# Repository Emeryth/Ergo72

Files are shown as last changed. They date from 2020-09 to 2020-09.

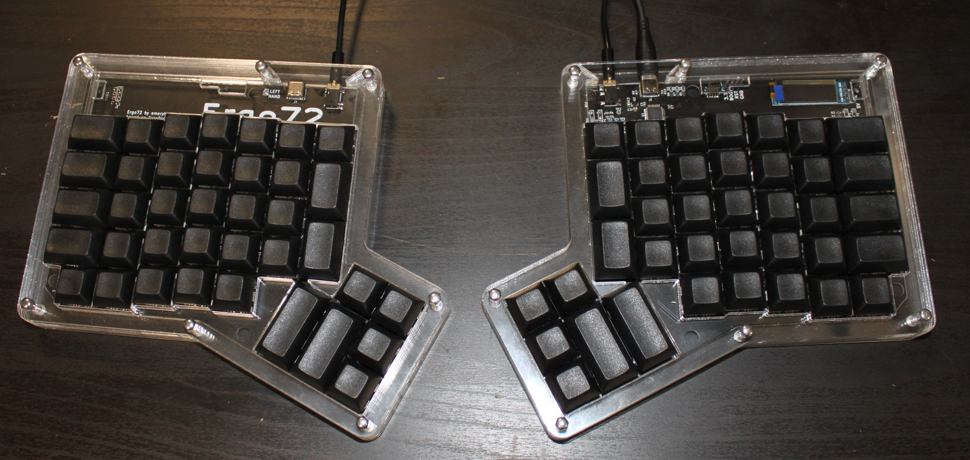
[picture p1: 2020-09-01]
pics/ergo72.jpg

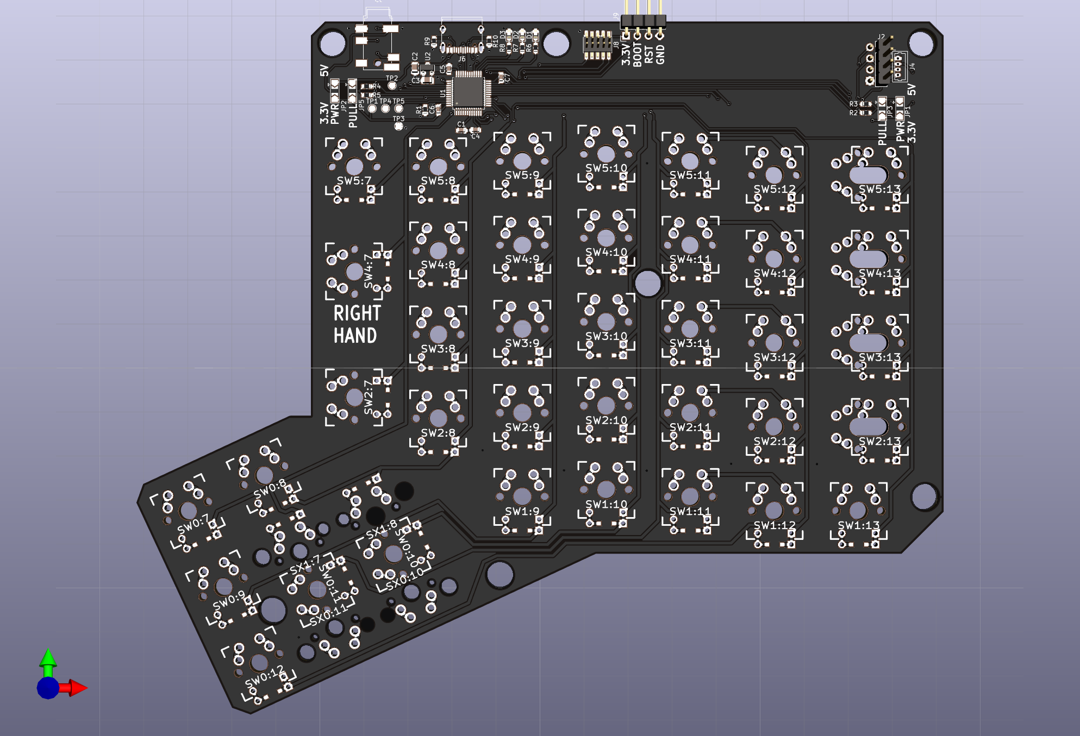
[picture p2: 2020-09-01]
pics/ErgoDOX.png

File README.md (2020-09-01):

# Ergo72

A redesigned ErgoDox keyboard PCB.
Check out [https://emeryth.net/ergo72-keyboard/](https://emeryth.net/ergo72-keyboard/) for more info.

Design features:

* Same key layout as the original Ergodox
* STM32 microcontroller (STM32F072)
* MCU in both halves allowing independent operation
* USB-C
* All components on PCB, no modules
* Extension header for OLED screen or anything else
* Single PCB for both hands
* QMK firmware supported

Basic acrylic case design included.

QMK firmware: [https://github.com/Emeryth/qmk_firmware/tree/ergo72](https://github.com/Emeryth/qmk_firmware/tree/ergo72)

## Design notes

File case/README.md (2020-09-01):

Acrylic case based on the original Ergodox case by Litster.

Layer stackup and thickness, from top to bottom:

1. Top 3mm
2. Spacer 4mm
3. Plate 4mm
4. Spacer 4mm
5. PCB support 3mm 
6. Bottom 3mm

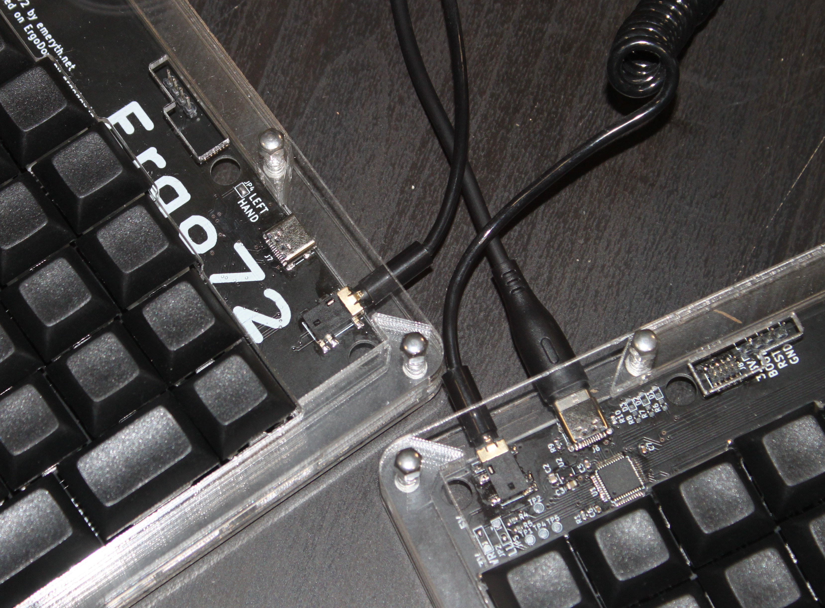
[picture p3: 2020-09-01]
pics/closeup.jpg

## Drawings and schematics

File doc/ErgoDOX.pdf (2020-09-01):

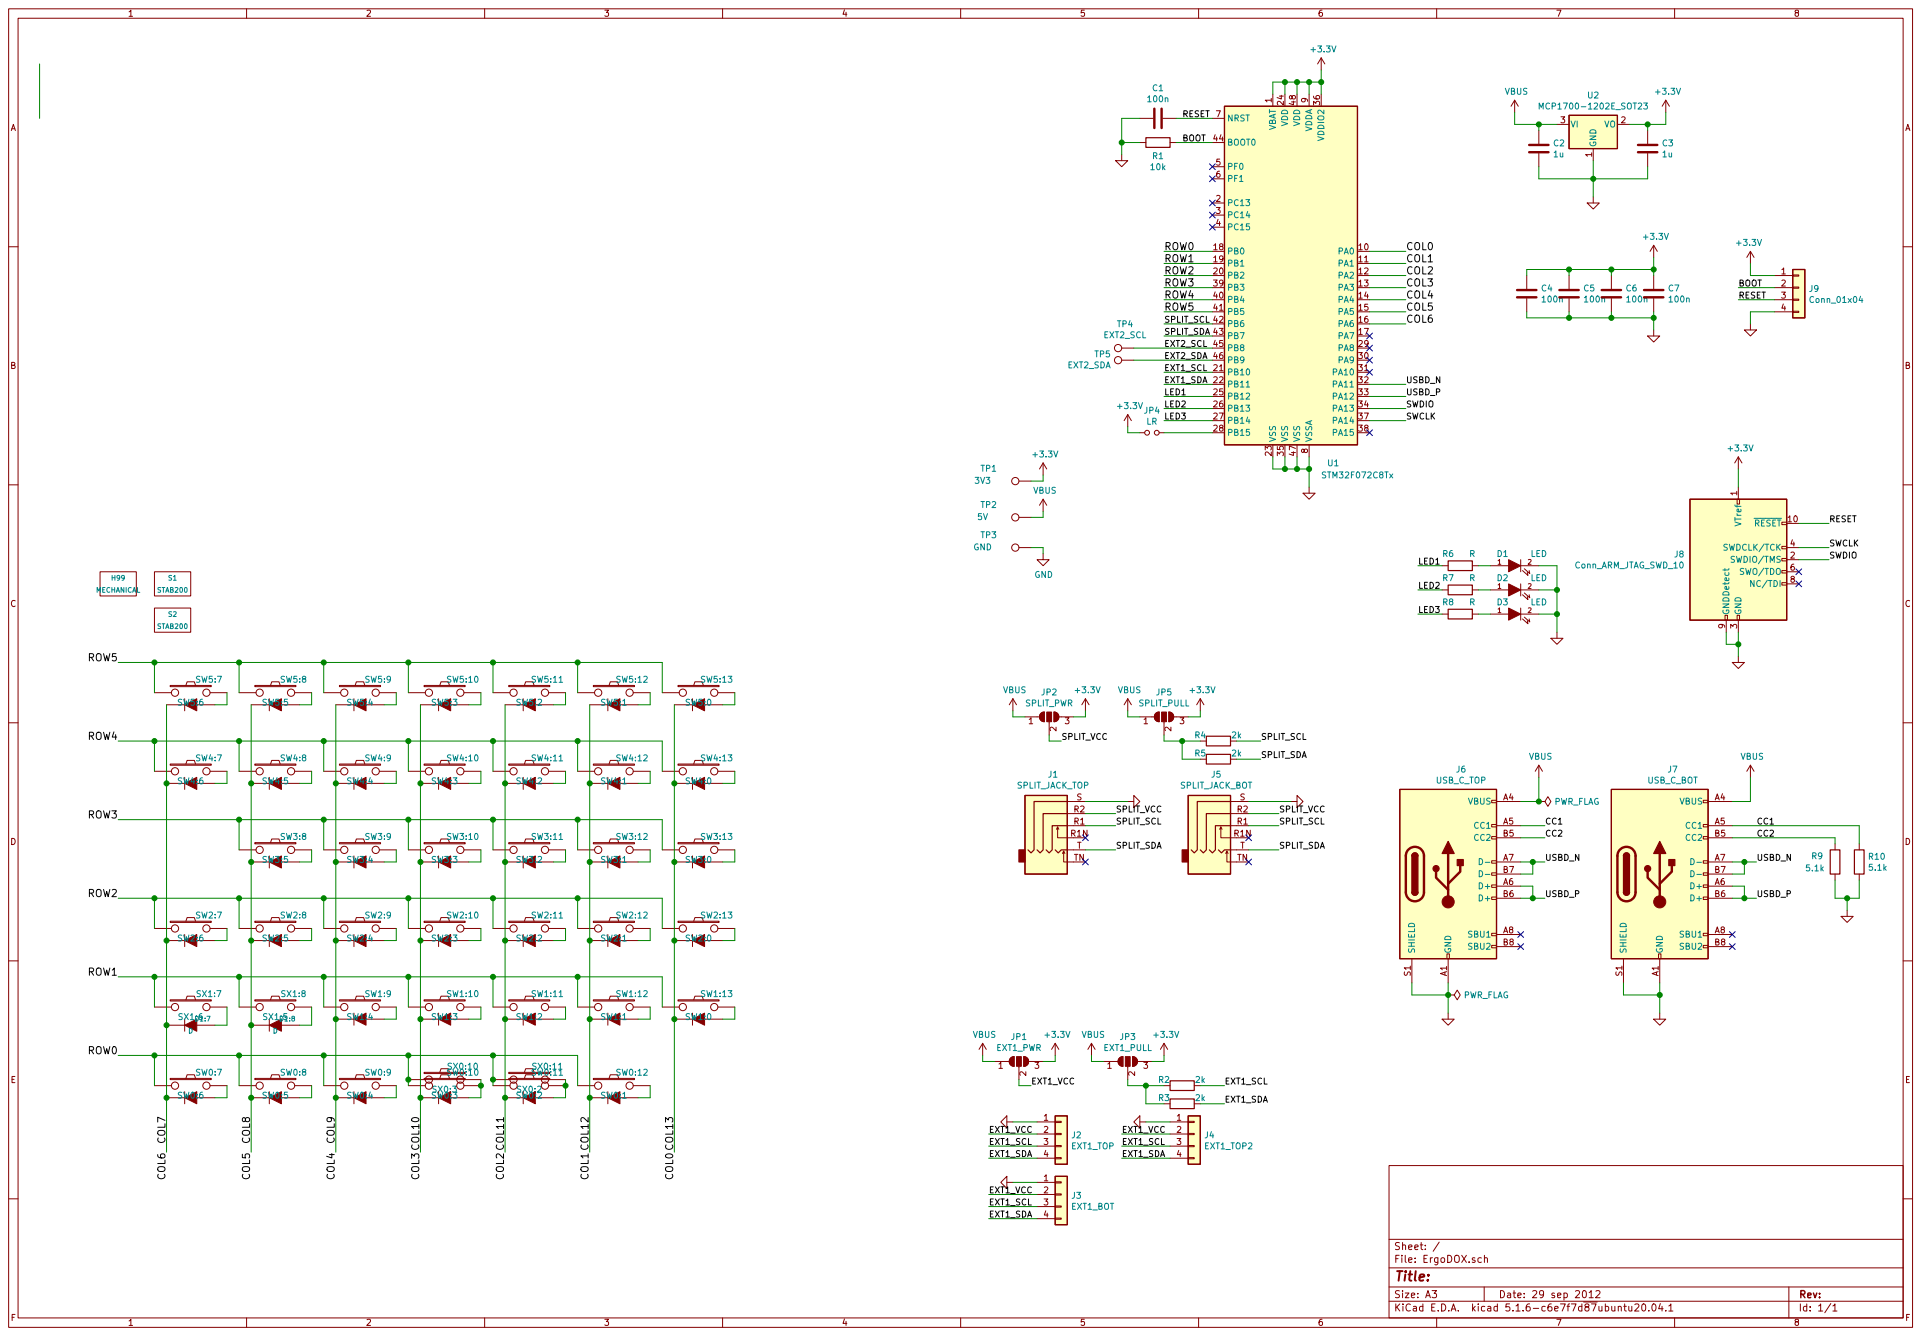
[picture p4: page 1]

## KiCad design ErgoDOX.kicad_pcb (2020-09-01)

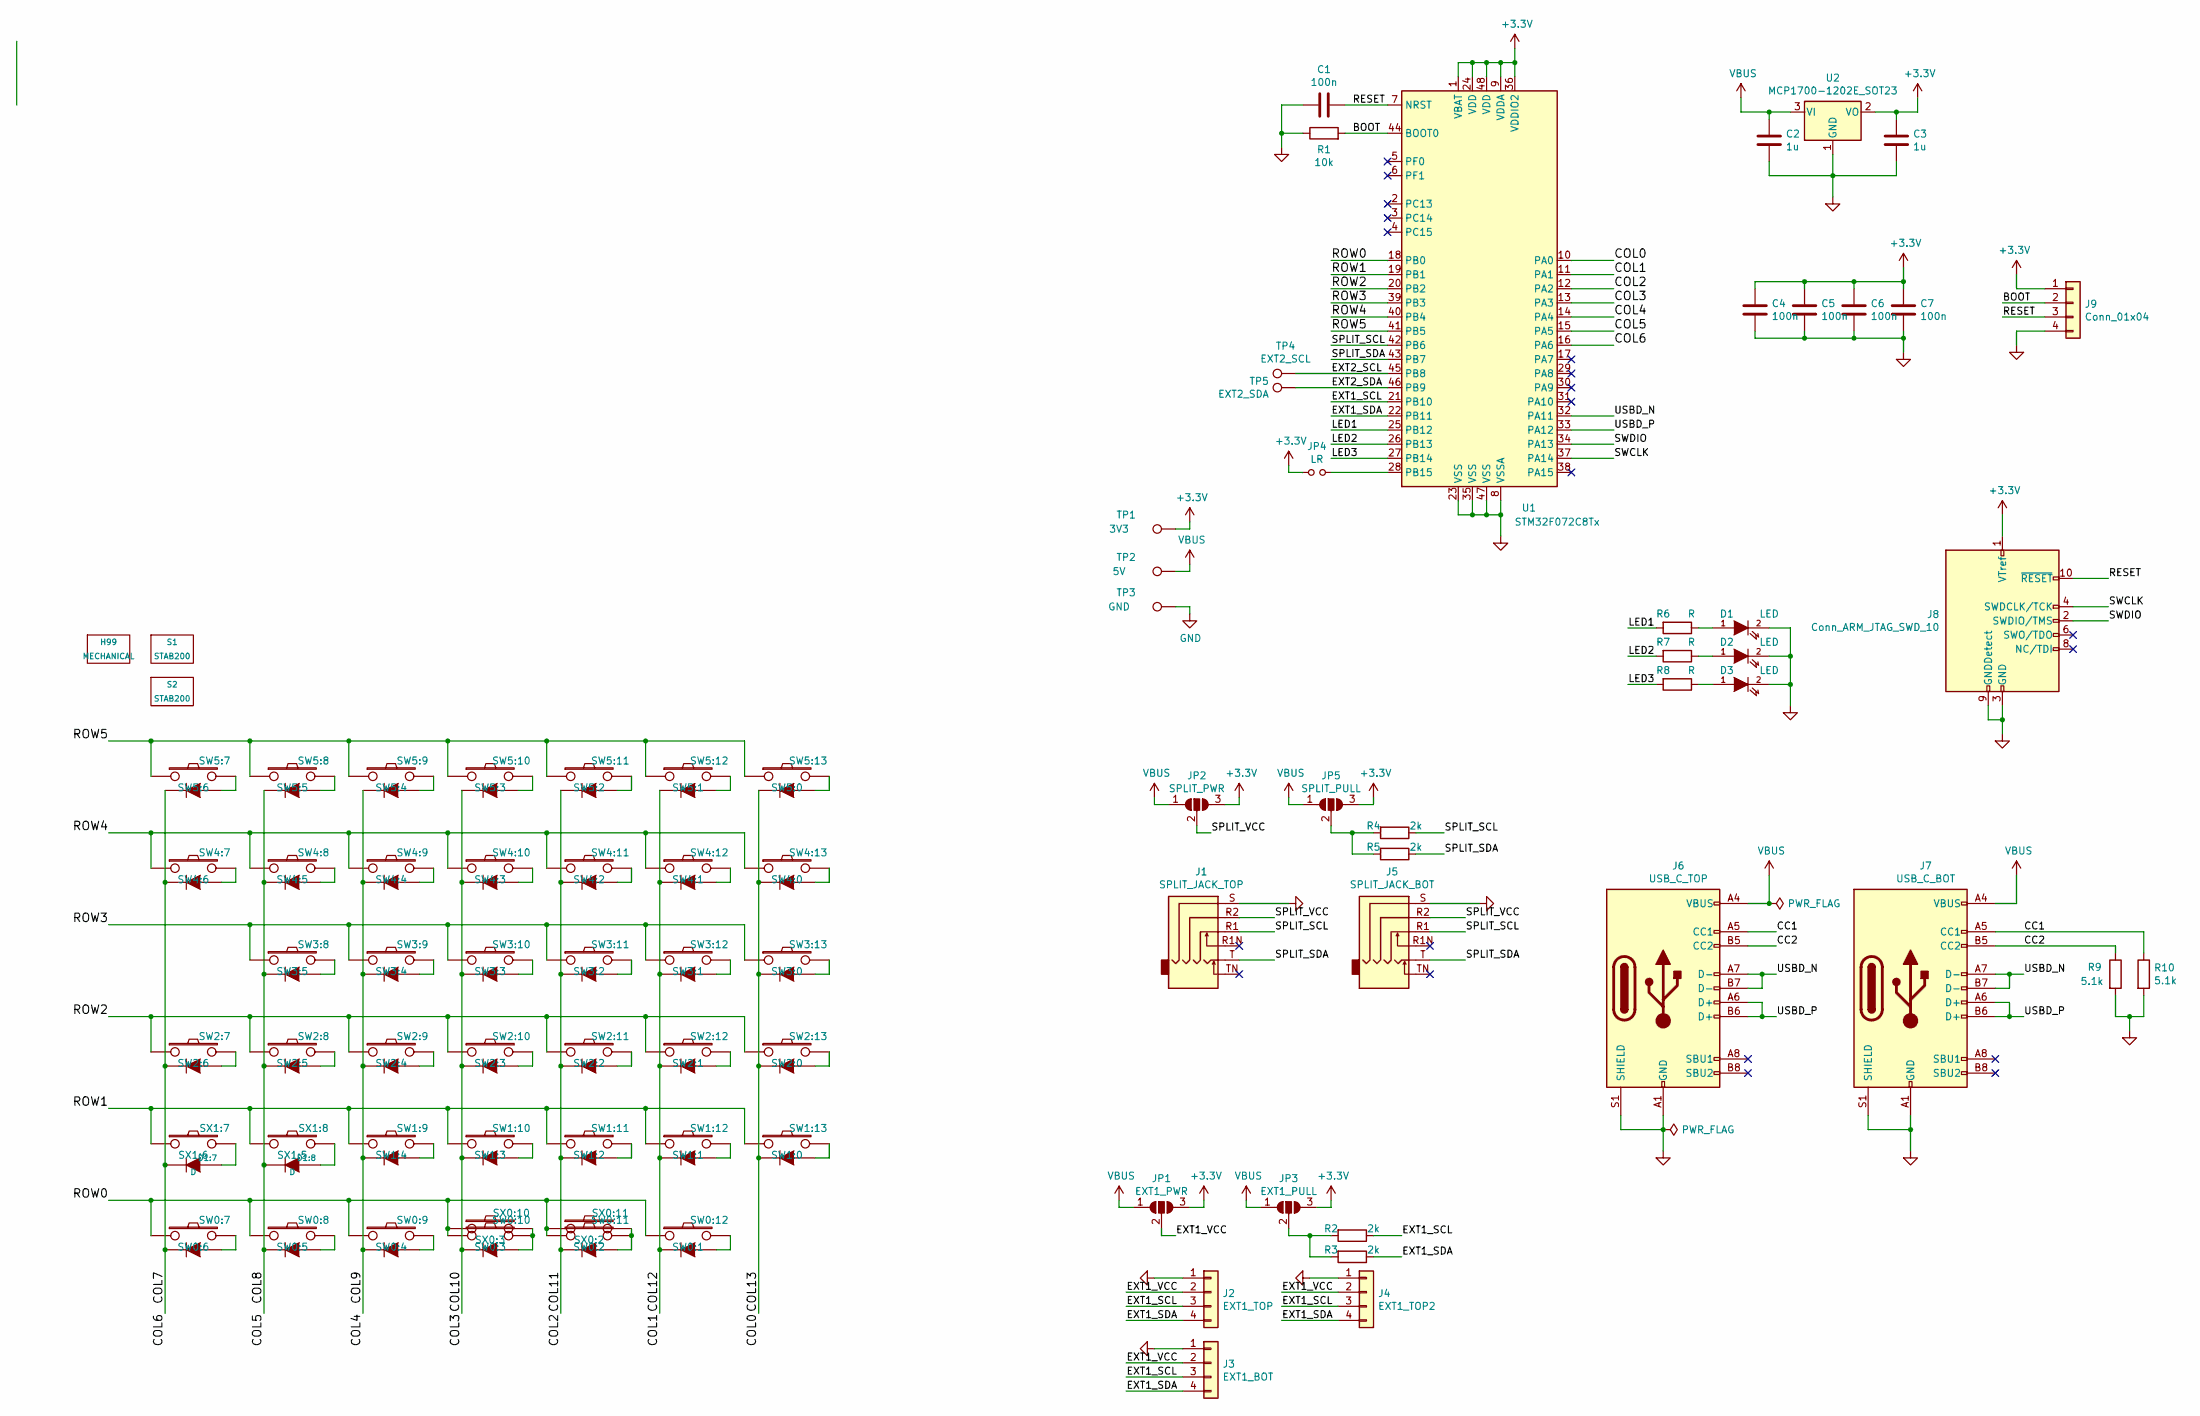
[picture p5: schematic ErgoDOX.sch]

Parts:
C1, C4, C5, C6, C7: 100n; C_0603_1608Metric
C2, C3: 1u; C_0805_2012Metric
D1, D2, D3: LED; LED_0603_1608Metric
D1:7, D1:8: D; DIODE
H99: MECHANICAL; ErgoDOXmech
J1: SPLIT_JACK_TOP; Jack_3.5mm_PJ31060-I_Horizontal
J2: EXT1_TOP; PinHeader_1x04_P2.54mm_Vertical
J3: EXT1_BOT; PinHeader_1x04_P2.54mm_Vertical
J4: EXT1_TOP2; Molex_PicoBlade_53047-0410_1x04_P1.25mm_Vertical
J5: SPLIT_JACK_BOT; Jack_3.5mm_PJ31060-I_Horizontal
J6: USB_C_TOP; USB_C_Receptacle_XKB_U262-16XN-4BVC11
J7: USB_C_BOT; USB_C_Receptacle_XKB_U262-16XN-4BVC11
J8: Conn_ARM_JTAG_SWD_10; PinHeader_2x05_P1.27mm_Vertical_SMD
J9: Conn_01x04; PinHeader_1x04_P2.54mm_Horizontal
JP1: EXT1_PWR; SolderJumper-3_P2.0mm_Open_TrianglePad1.0x1.5mm
JP2: SPLIT_PWR; SolderJumper-3_P2.0mm_Open_TrianglePad1.0x1.5mm
JP3: EXT1_PULL; SolderJumper-3_P2.0mm_Open_TrianglePad1.0x1.5mm
JP4: LR; SolderJumper-2_P1.3mm_Open_TrianglePad1.0x1.5mm
JP5: SPLIT_PULL; SolderJumper-3_P2.0mm_Open_TrianglePad1.0x1.5mm
R1: 10k; R_0603_1608Metric
R2, R3, R4, R5: 2k; R_0603_1608Metric
R6, R7, R8: R; R_0603_1608Metric
R9, R10: 5.1k; R_0603_1608Metric
S1, S2: STAB200
SW0:7: SW0:6; MX_FLIP_DIODE
SW0:8: SW0:5; MX_FLIP_DIODE
SW0:9: SW0:4; MX_FLIP_DIODE
SW0:10: SW0:3; MX_FLIP_DIODE
SW0:11: SW0:2; MX_FLIP_DIODE
SW0:12: SW0:1; MX_FLIP_DIODE
SW1:9: SW1:4; MX_FLIP_DIODE
SW1:10: SW1:3; MX_FLIP_DIODE
SW1:11: SW1:2; MX_FLIP_DIODE
SW1:12: SW1:1; MX_FLIP_DIODE
SW1:13: SW1:0; MX_FLIP_DIODE
SW2:7: SW2:6; MX_FLIP_DIODE
SW2:8: SW2:5; MX_FLIP_DIODE
SW2:9: SW2:4; MX_FLIP_DIODE
SW2:10: SW2:3; MX_FLIP_DIODE
SW2:11: SW2:2; MX_FLIP_DIODE
SW2:12: SW2:1; MX_FLIP_DIODE
SW2:13: SW2:0; MX_FLIP_XX
SW3:8: SW3:5; MX_FLIP_DIODE
SW3:9: SW3:4; MX_FLIP_DIODE
SW3:10: SW3:3; MX_FLIP_DIODE
SW3:11: SW3:2; MX_FLIP_DIODE
SW3:12: SW3:1; MX_FLIP_DIODE
SW3:13: SW3:0; MX_FLIP_XX
SW4:7: SW4:6; MX_FLIP_DIODE
SW4:8: SW4:5; MX_FLIP_DIODE
SW4:9: SW4:4; MX_FLIP_DIODE
SW4:10: SW4:3; MX_FLIP_DIODE
SW4:11: SW4:2; MX_FLIP_DIODE
SW4:12: SW4:1; MX_FLIP_DIODE
SW4:13: SW4:0; MX_FLIP_XX
SW5:7: SW5:6; MX_FLIP_DIODE
SW5:8: SW5:5; MX_FLIP_DIODE
SW5:9: SW5:4; MX_FLIP_DIODE
SW5:10: SW5:3; MX_FLIP_DIODE
SW5:11: SW5:2; MX_FLIP_DIODE
SW5:12: SW5:1; MX_FLIP_DIODE
SW5:13: SW5:0; MX_FLIP_XX
SX0:10: SX0:3; MX_FLIP
SX0:11: SX0:2; MX_FLIP
SX1:7: SX1:6; MX_FLIP
SX1:8: SX1:5; MX_FLIP
TP1: 3V3; TestPoint_Pad_D1.5mm
TP2: 5V; TestPoint_Pad_D1.5mm
TP3: GND; TestPoint_Pad_D1.5mm
TP4: EXT2_SCL; TestPoint_Pad_D1.5mm
TP5: EXT2_SDA; TestPoint_Pad_D1.5mm
U1: STM32F072C8Tx; LQFP-48_7x7mm_P0.5mm
U2: MCP1700-1202E_SOT23; SOT-23

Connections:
+3V3: C3.1, C4.1, C5.1, C6.1, C7.1, J8.1 (VTref), J9.1, JP1.3 (B), JP2.3 (B), JP3.3 (B), JP4.1, JP5.3 (B), TP1.1, U1.1 (VBAT), U1.9 (VDDA), U1.24 (VDD), U1.36 (VDDIO2), U1.48 (VDD), U2.2 (VO)
/BOOT: J9.2, R1.2, U1.44 (BOOT0)
/CC1: J6.A5 (CC1), J7.A5 (CC1), R10.1
/CC2: J6.B5 (CC2), J7.B5 (CC2), R9.1
/COL0: SW1:13.4 (K), SW2:13.4 (K), SW3:13.4 (K), SW4:13.4 (K), SW5:13.4 (K), U1.10 (PA0)
/COL1: SW0:12.4 (K), SW1:12.4 (K), SW2:12.4 (K), SW3:12.4 (K), SW4:12.4 (K), SW5:12.4 (K), U1.11 (PA1)
/COL4: SW0:9.4 (K), SW1:9.4 (K), SW2:9.4 (K), SW3:9.4 (K), SW4:9.4 (K), SW5:9.4 (K), U1.14 (PA4)
/COL5: D1:8.2 (K), SW0:8.4 (K), SW2:8.4 (K), SW3:8.4 (K), SW4:8.4 (K), SW5:8.4 (K), U1.15 (PA5)
/COL6: D1:7.2 (K), SW0:7.4 (K), SW2:7.4 (K), SW4:7.4 (K), SW5:7.4 (K), U1.16 (PA6)
/COL10: SW0:10.4 (K), SW1:10.4 (K), SW2:10.4 (K), SW3:10.4 (K), SW4:10.4 (K), SW5:10.4 (K), U1.13 (PA3)
/COL11: SW0:11.4 (K), SW1:11.4 (K), SW2:11.4 (K), SW3:11.4 (K), SW4:11.4 (K), SW5:11.4 (K), U1.12 (PA2)
/EXT1_SCL: J2.3, J3.3, J4.3, R2.1, U1.21 (PB10)
/EXT1_SDA: J2.4, J3.4, J4.4, R3.1, U1.22 (PB11)
/EXT1_VCC: J2.2, J3.2, J4.2, JP1.2 (C)
/EXT2_SCL: TP4.1, U1.45 (PB8)
/EXT2_SDA: TP5.1, U1.46 (PB9)
/LED1: R6.2, U1.25 (PB12)
/LED2: R7.2, U1.26 (PB13)
/LED3: R8.2, U1.27 (PB14)
/RESET: C1.1, J8.10 (~RESET~), J9.3, U1.7 (NRST)
/ROW0: SW0:7.1, SW0:8.1, SW0:9.1, SW0:10.1, SW0:11.1, SW0:12.1, SX0:10.1, SX0:11.1, U1.18 (PB0)
/ROW1: SW1:9.1, SW1:10.1, SW1:11.1, SW1:12.1, SW1:13.1, SX1:7.1, SX1:8.1, U1.19 (PB1)
/ROW2: SW2:7.1, SW2:8.1, SW2:9.1, SW2:10.1, SW2:11.1, SW2:12.1, SW2:13.1, U1.20 (PB2)
/ROW3: SW3:8.1, SW3:9.1, SW3:10.1, SW3:11.1, SW3:12.1, SW3:13.1, U1.39 (PB3)
/ROW4: SW4:7.1, SW4:8.1, SW4:9.1, SW4:10.1, SW4:11.1, SW4:12.1, SW4:13.1, U1.40 (PB4)
/ROW5: SW5:7.1, SW5:8.1, SW5:9.1, SW5:10.1, SW5:11.1, SW5:12.1, SW5:13.1, U1.41 (PB5)
/SPLIT_SCL: J1.R1, J5.R1, R4.1, U1.42 (PB6)
/SPLIT_SDA: J1.T, J5.T, R5.1, U1.43 (PB7)
/SPLIT_VCC: J1.R2, J5.R2, JP2.2 (C)
/SWCLK: J8.4 (SWDCLK/TCK), U1.37 (PA14)
/SWDIO: J8.2 (SWDIO/TMS), U1.34 (PA13)
/USBD_N: J6.A7 (D-), J6.B7 (D-), J7.A7 (D-), J7.B7 (D-), U1.32 (PA11)
/USBD_P: J6.A6 (D+), J6.B6 (D+), J7.A6 (D+), J7.B6 (D+), U1.33 (PA12)
GND: C1.2, C2.2, C3.2, C4.2, C5.2, C6.2, C7.2, D1.2 (K), D2.2 (K), D3.2 (K), J1.S, J2.1, J3.1, J4.1, J5.S, J6.A1 (GND), J6.A12 (GND), J6.B1 (GND), J6.B12 (GND), J6.S1 (SHIELD), J7.A1 (GND), J7.A12 (GND), J7.B1 (GND), J7.B12 (GND), J7.S1 (SHIELD), J8.3 (GND), J8.5 (GND), J8.9 (GNDDetect), J9.4, R1.1, R9.2, R10.2, TP3.1, U1.8 (VSSA), U1.23 (VSS), U1.35 (VSS), U1.47 (VSS), U2.1 (GND); also elsewhere on the board
unnamed: D1.1 (A), R6.1
unnamed: D1:7.1 (A), SX1:7.2
unnamed: D1:8.1 (A), SX1:8.2
unnamed: D2.1 (A), R7.1
unnamed: D3.1 (A), R8.1
unnamed: JP3.2 (C), R2.2, R3.2
unnamed: JP4.2, U1.28 (PB15)
unnamed: JP5.2 (C), R4.2, R5.2
unnamed: SW0:7.2, SW0:7.3 (A)
unnamed: SW0:8.2, SW0:8.3 (A)
unnamed: SW0:9.2, SW0:9.3 (A)
unnamed: SW0:10.2, SW0:10.3 (A), SX0:10.2
unnamed: SW0:11.2, SW0:11.3 (A), SX0:11.2
unnamed: SW0:12.2, SW0:12.3 (A)
unnamed: SW1:9.2, SW1:9.3 (A)
unnamed: SW1:10.2, SW1:10.3 (A)
unnamed: SW1:11.2, SW1:11.3 (A)
unnamed: SW1:12.2, SW1:12.3 (A)
unnamed: SW1:13.2, SW1:13.3 (A)
unnamed: SW2:7.2, SW2:7.3 (A)
unnamed: SW2:8.2, SW2:8.3 (A)
unnamed: SW2:9.2, SW2:9.3 (A)
unnamed: SW2:10.2, SW2:10.3 (A)
unnamed: SW2:11.2, SW2:11.3 (A)
unnamed: SW2:12.2, SW2:12.3 (A)
unnamed: SW2:13.2, SW2:13.3 (A)
unnamed: SW3:8.2, SW3:8.3 (A)
unnamed: SW3:9.2, SW3:9.3 (A)
unnamed: SW3:10.2, SW3:10.3 (A)
unnamed: SW3:11.2, SW3:11.3 (A)
unnamed: SW3:12.2, SW3:12.3 (A)
unnamed: SW3:13.2, SW3:13.3 (A)
unnamed: SW4:7.2, SW4:7.3 (A)
unnamed: SW4:8.2, SW4:8.3 (A)
unnamed: SW4:9.2, SW4:9.3 (A)
unnamed: SW4:10.2, SW4:10.3 (A)
unnamed: SW4:11.2, SW4:11.3 (A)
unnamed: SW4:12.2, SW4:12.3 (A)
unnamed: SW4:13.2, SW4:13.3 (A)
unnamed: SW5:7.2, SW5:7.3 (A)
unnamed: SW5:8.2, SW5:8.3 (A)
unnamed: SW5:9.2, SW5:9.3 (A)
unnamed: SW5:10.2, SW5:10.3 (A)
unnamed: SW5:11.2, SW5:11.3 (A)
unnamed: SW5:12.2, SW5:12.3 (A)
unnamed: SW5:13.2, SW5:13.3 (A)
VBUS: C2.1, J6.A4 (VBUS), J6.A9 (VBUS), J6.B4 (VBUS), J6.B9 (VBUS), J7.A4 (VBUS), J7.A9 (VBUS), J7.B4 (VBUS), J7.B9 (VBUS), JP1.1 (A), JP2.1 (A), JP3.1 (A), JP5.1 (A), TP2.1, U2.3 (VI)

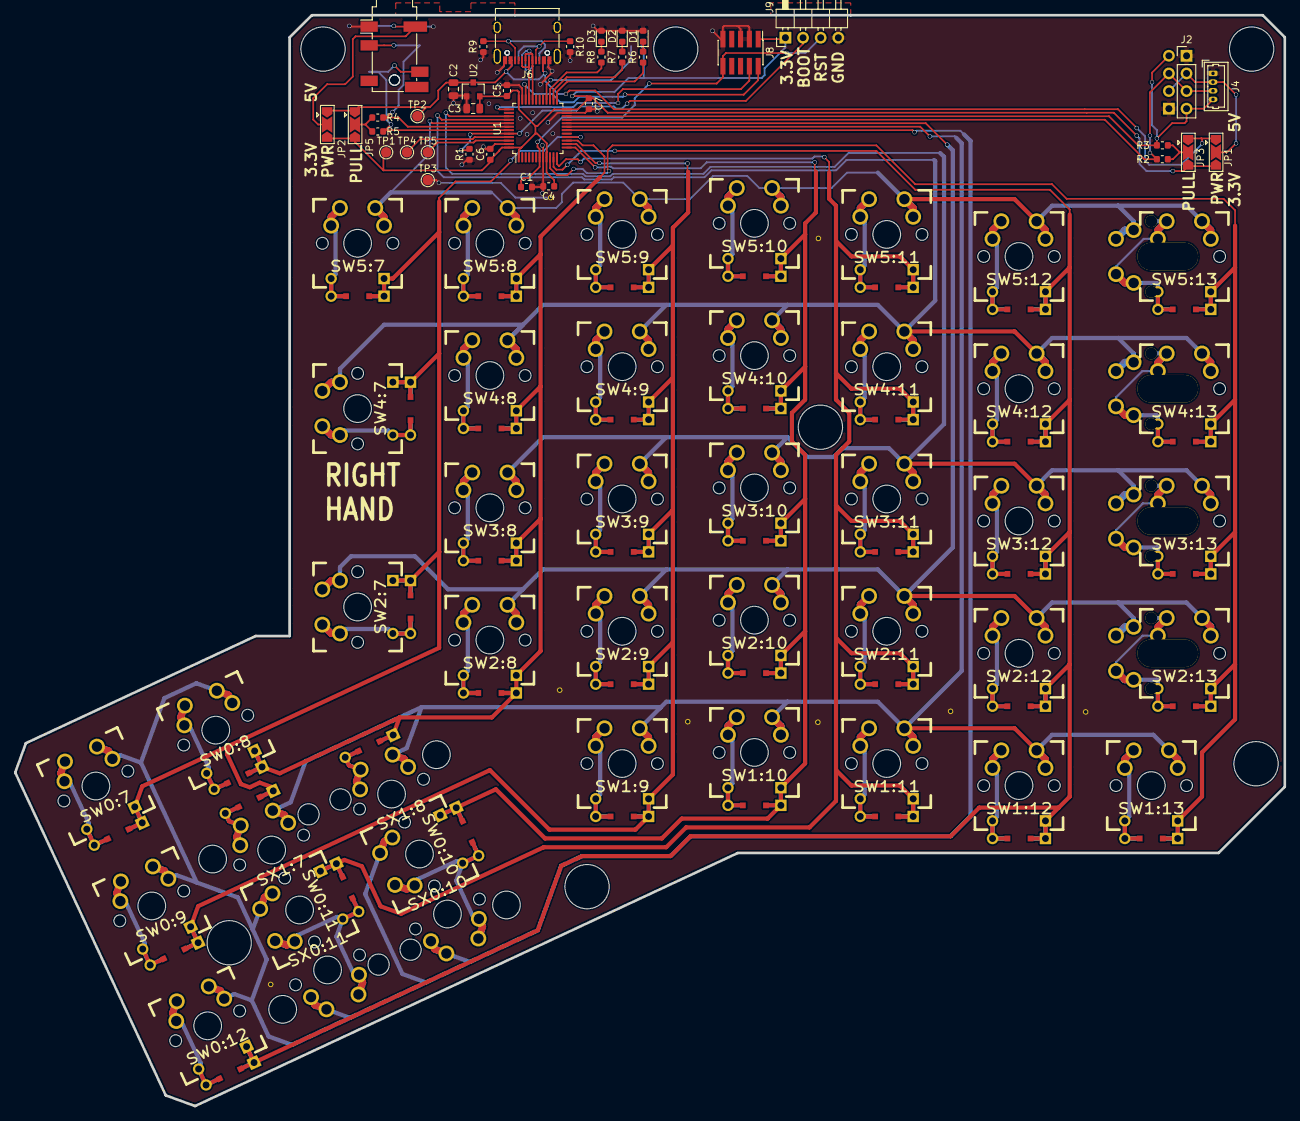
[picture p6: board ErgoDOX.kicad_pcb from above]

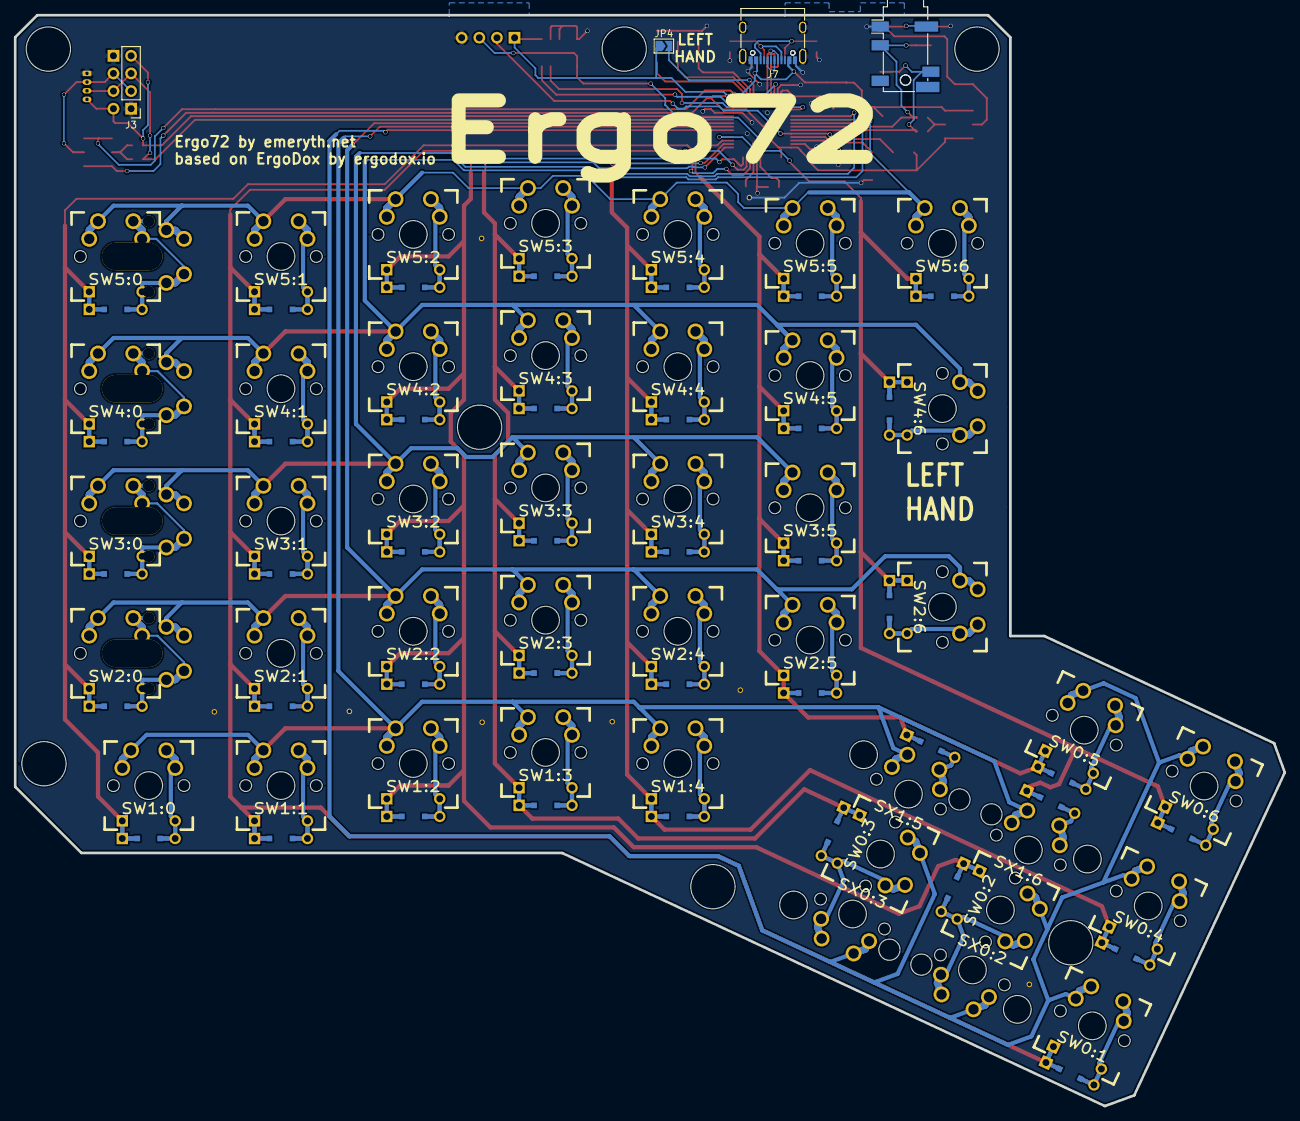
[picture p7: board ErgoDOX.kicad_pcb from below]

Board: 2 copper layers, 182.8 x 157.1 mm, 96 parts (4 on the bottom side), 81 nets.

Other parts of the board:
STITCHING_VIA: STITCHING_VIA
STITCHING_VIA#2, STITCHING_VIA#3, STITCHING_VIA#4, STITCHING_VIA#5, STITCHING_VIA#6, STITCHING_VIA#7, STITCHING_VIA#8: STITCHING_VIA

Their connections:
GND: STITCHING_VIA.GND, STITCHING_VIA#2.GND, STITCHING_VIA#3.GND, STITCHING_VIA#4.GND, STITCHING_VIA#5.GND, STITCHING_VIA#6.GND, STITCHING_VIA#7.GND, STITCHING_VIA#8.GND; also elsewhere on the board

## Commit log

2020-07-19 Initial commit.
    [ErgoDOX.brd, ErgoDOX.kicad_pcb, ErgoDOX.sch]
2020-07-19 Assign footprints to old and new components.
    [ErgoDOX.kicad_pcb, ErgoDOX.sch]
2020-07-27 Routing done, needs review.
    [ErgoDOX.kicad_pcb, ErgoDOX.sch]
2020-08-02 Add testpoints and fix some stuff.
    [ErgoDOX.kicad_pcb, ErgoDOX.sch]
2020-09-01 Final version sent to the fab.
    [ErgoDOX-B_Mask.gbs, ErgoDOX-B_SilkS.gbo, ErgoDOX-Back.gbl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]
